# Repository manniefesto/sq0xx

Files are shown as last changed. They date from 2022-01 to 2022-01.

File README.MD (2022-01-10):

# Sq0xx

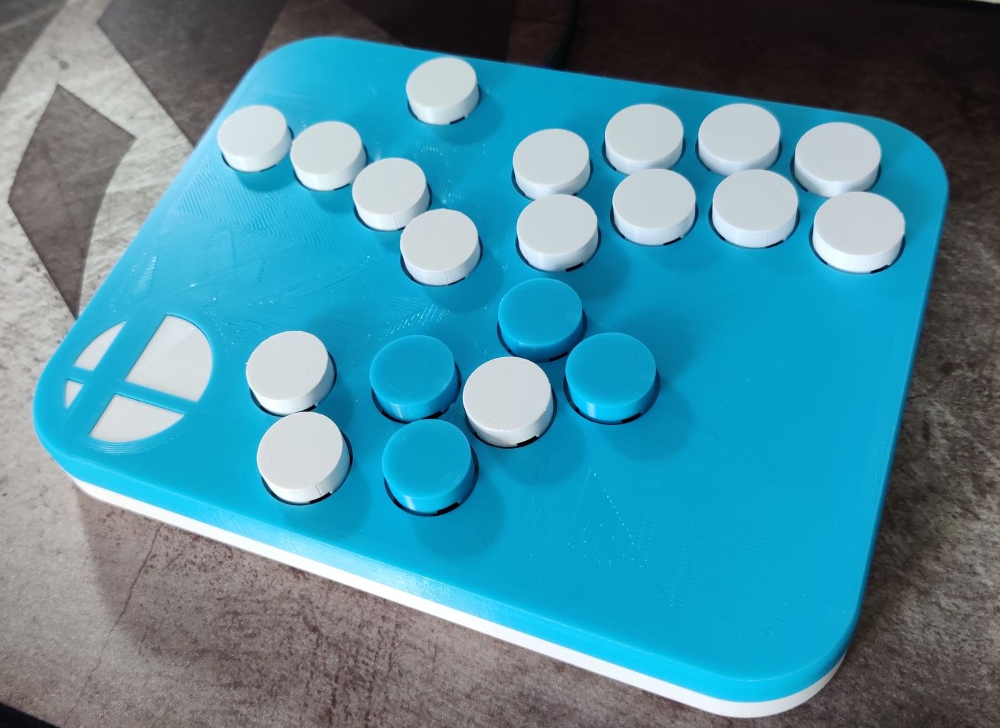
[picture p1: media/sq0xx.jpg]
Image of sq0xx


Squat b0xx.

I've printed and tested V1, there are some fixes in the V2 case files that are untested but should work just fine.

## V1 vs V2
I made a few small changes to the way that the two halves connect.

* Increased the size of the inset to make a tighter fit.
* Moved the magnets closer together.

## 3D Printed parts
* 1 x Top.stl
* 1 x Plate.stl
* 1 x TopLogo.stl
* 1 x Bottom.stl
* 20 x [20mm MX button](https://cdn.thingiverse.com/assets/29/e4/cd/0b/65/20.64mm_Keycap.stl) from the [Fake1](https://www.thingiverse.com/thing:4917086)

## BOM
* PCB, I suggest JLCPCB.
* 20 MX keyboard switches.
* 20 Kailh hot swap sockets.
* Raspberry Pico micro controller.
* M2 Standoffs [Amazon link](https://www.amazon.co.uk/gp/product/B08LDF5SMQ)
* 4 10mm x 3mm magnets [Amazon link](https://www.amazon.co.uk/gp/product/B07QKWBS4S)

## Soldering
All of the components are soldered on to the back of the PCB. The Pico is soldered flat against the board without a socket. I have added break outs for a hardwired GCC cable if required.

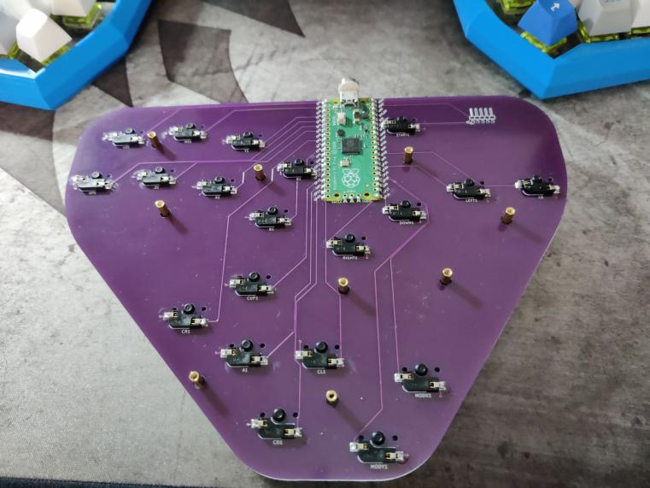
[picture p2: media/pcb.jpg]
Image of pcb


## Firmware
Big shout out to Arte for writing some awesome software, [pico-rectangle](https://github.com/JulienBernard3383279/pico-rectangle)

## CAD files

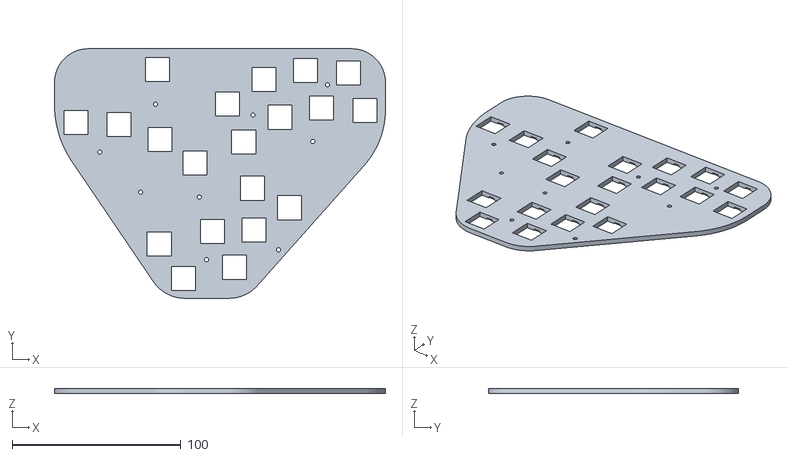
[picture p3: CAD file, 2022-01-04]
Case/V2/Plate.stl
196.1 x 147.9 x 3.00

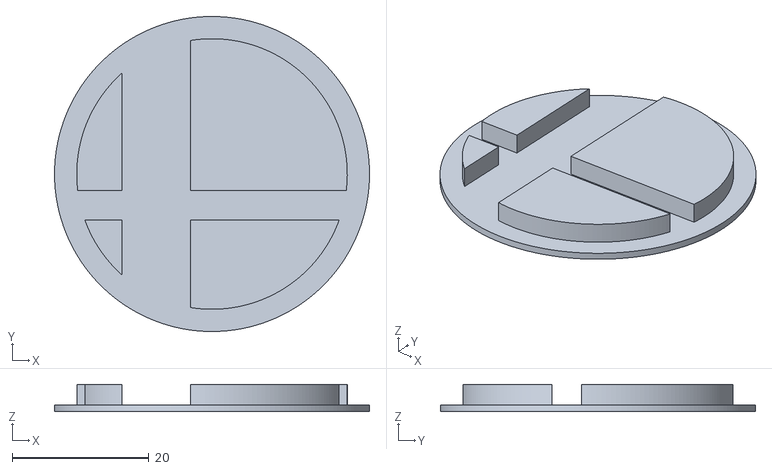
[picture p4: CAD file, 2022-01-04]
Case/V2/TopLogo.stl
46.0 x 46.0 x 4.00

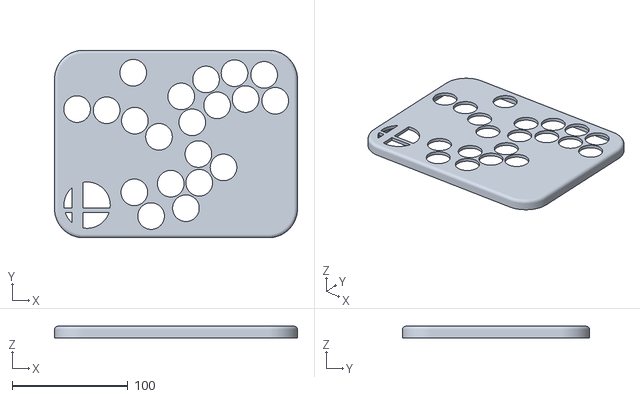
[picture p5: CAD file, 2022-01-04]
Case/V2/Top.stl
210.0 x 162.0 x 10.0

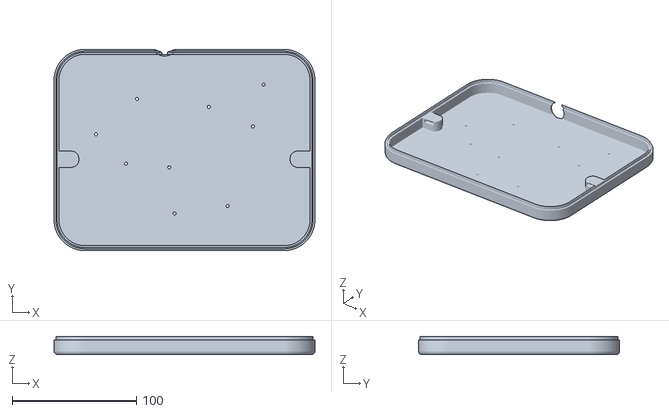
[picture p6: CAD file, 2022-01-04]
Case/V2/Bottom.stl
210.0 x 162.0 x 14.8

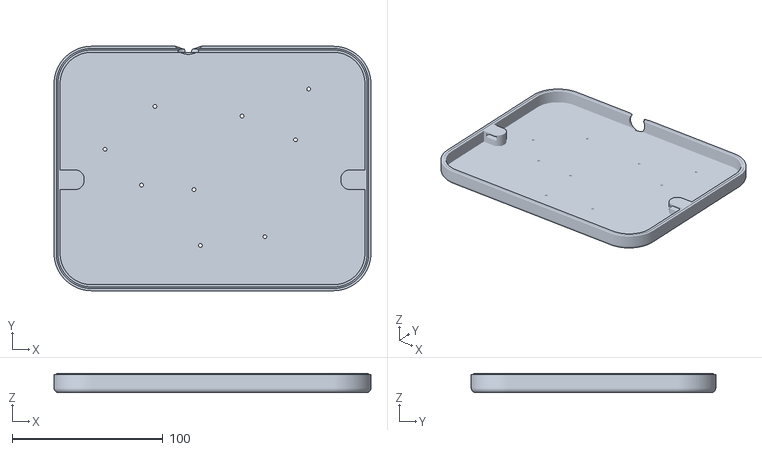
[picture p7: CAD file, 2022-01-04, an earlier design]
Case/V1/Bottom.stl
210.0 x 162.0 x 12.8

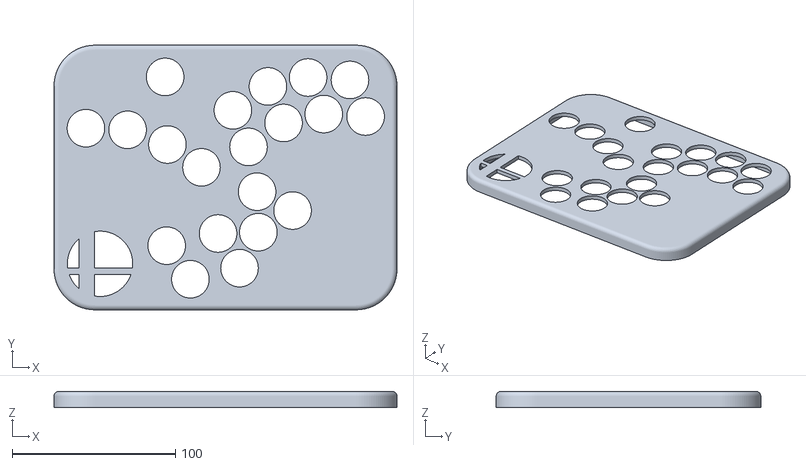
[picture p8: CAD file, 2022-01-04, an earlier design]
Case/V1/Top.stl
210.0 x 162.0 x 10.0

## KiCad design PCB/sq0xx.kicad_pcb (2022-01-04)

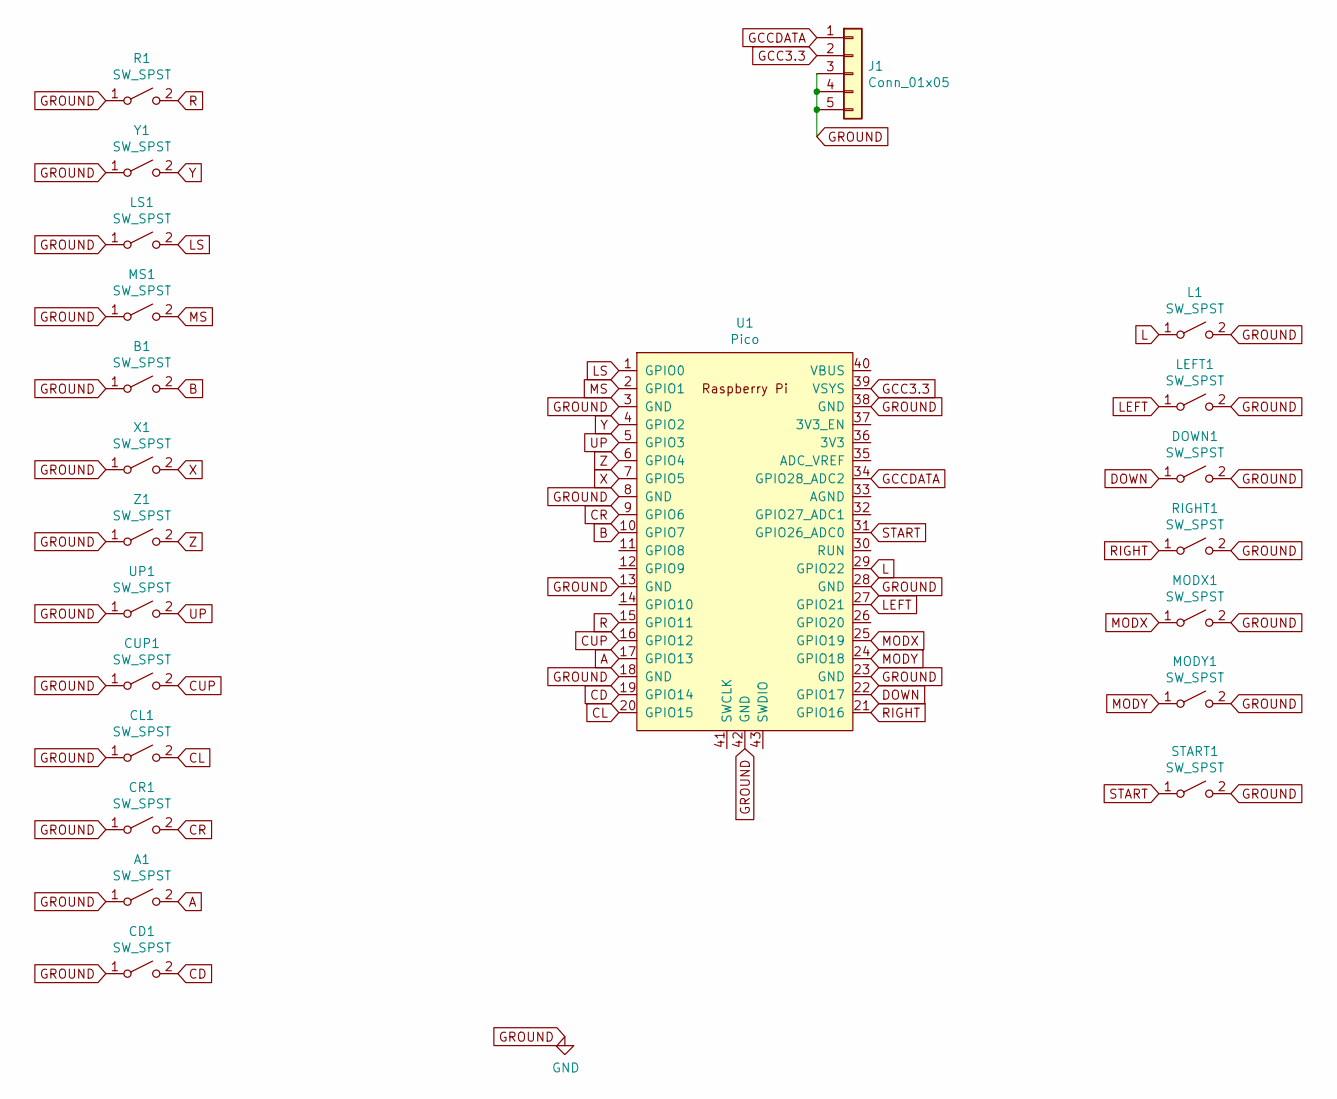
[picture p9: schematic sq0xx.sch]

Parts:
A1: SW_SPST; SW_Hotswap_Kailh
B1: SW_SPST; SW_Hotswap_Kailh
CD1: SW_SPST; SW_Hotswap_Kailh
CL1: SW_SPST; SW_Hotswap_Kailh
CR1: SW_SPST; SW_Hotswap_Kailh
CUP1: SW_SPST; SW_Hotswap_Kailh
DOWN1: SW_SPST; SW_Hotswap_Kailh
J1: Conn_01x05; PinHeader_1x05_P2.00mm_Vertical
L1: SW_SPST; SW_Hotswap_Kailh
LEFT1: SW_SPST; SW_Hotswap_Kailh
LS1: SW_SPST; SW_Hotswap_Kailh
MODX1: SW_SPST; SW_Hotswap_Kailh
MODY1: SW_SPST; SW_Hotswap_Kailh
MS1: SW_SPST; SW_Hotswap_Kailh
R1: SW_SPST; SW_Hotswap_Kailh
RIGHT1: SW_SPST; SW_Hotswap_Kailh
START1: SW_SPST; SW_Hotswap_Kailh
U1: Pico; RPi_Pico_SMD_TH
UP1: SW_SPST; SW_Hotswap_Kailh
X1: SW_SPST; SW_Hotswap_Kailh
Y1: SW_SPST; SW_Hotswap_Kailh
Z1: SW_SPST; SW_Hotswap_Kailh

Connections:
A: A1.2 (B), U1.17 (GPIO13)
B: B1.2 (B), U1.10 (GPIO7)
CD: CD1.2 (B), U1.19 (GPIO14)
CL: CL1.2 (B), U1.20 (GPIO15)
CR: CR1.2 (B), U1.9 (GPIO6)
CUP: CUP1.2 (B), U1.16 (GPIO12)
DOWN: DOWN1.1 (A), U1.22 (GPIO17)
GCC3.3: J1.2, U1.39 (VSYS)
GCCDATA: J1.1, U1.34 (GPIO28_ADC2)
GROUND: A1.1 (A), B1.1 (A), CD1.1 (A), CL1.1 (A), CR1.1 (A), CUP1.1 (A), DOWN1.2 (B), J1.3, J1.4, J1.5, L1.2 (B), LEFT1.2 (B), LS1.1 (A), MODX1.2 (B), MODY1.2 (B), MS1.1 (A), R1.1 (A), RIGHT1.2 (B), START1.2 (B), U1.3 (GND), U1.8 (GND), U1.13 (GND), U1.18 (GND), U1.23 (GND), U1.28 (GND), U1.38 (GND), U1.42 (GND), UP1.1 (A), X1.1 (A), Y1.1 (A), Z1.1 (A)
L: L1.1 (A), U1.29 (GPIO22)
LEFT: LEFT1.1 (A), U1.27 (GPIO21)
LS: LS1.2 (B), U1.1 (GPIO0)
MODX: MODX1.1 (A), U1.25 (GPIO19)
MODY: MODY1.1 (A), U1.24 (GPIO18)
MS: MS1.2 (B), U1.2 (GPIO1)
R: R1.2 (B), U1.15 (GPIO11)
RIGHT: RIGHT1.1 (A), U1.21 (GPIO16)
START: START1.1 (A), U1.31 (GPIO26_ADC0)
UP: U1.5 (GPIO3), UP1.2 (B)
X: U1.7 (GPIO5), X1.2 (B)
Y: U1.4 (GPIO2), Y1.2 (B)
Z: U1.6 (GPIO4), Z1.2 (B)

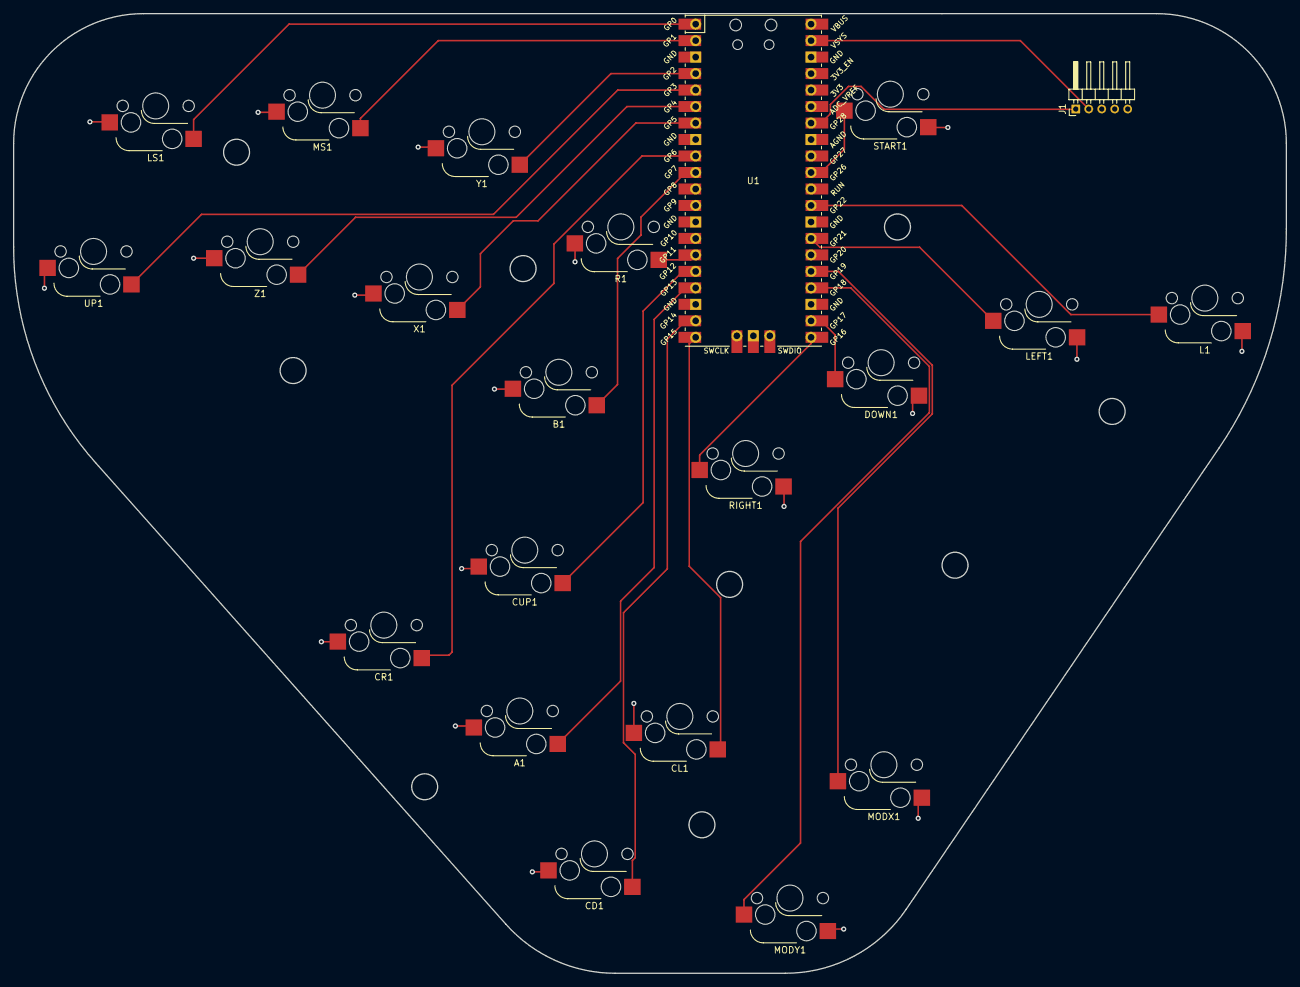
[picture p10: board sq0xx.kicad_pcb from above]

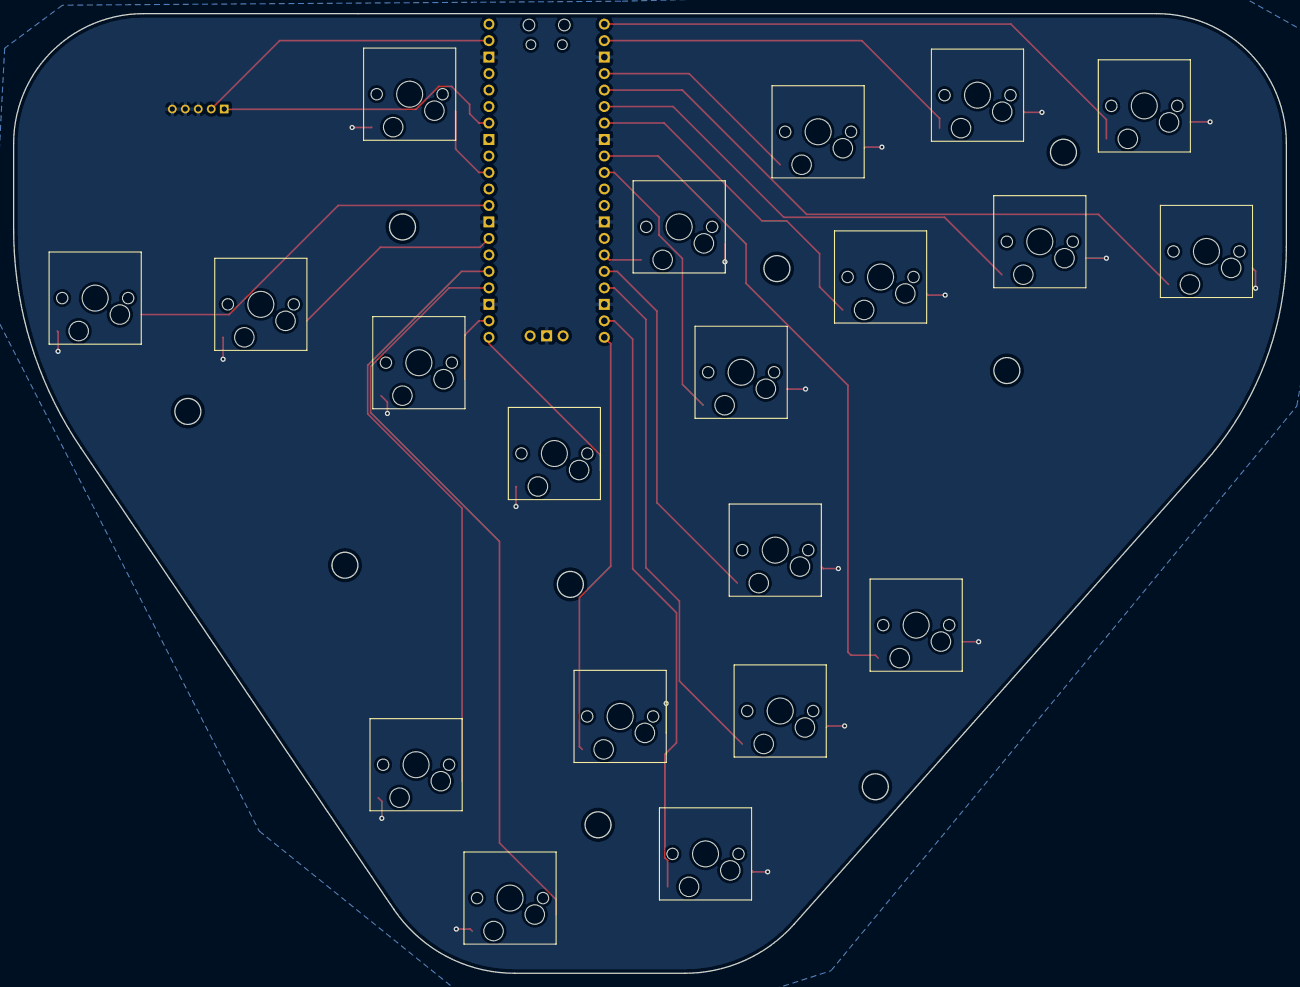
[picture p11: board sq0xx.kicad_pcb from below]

Board: 2 copper layers, 196.1 x 147.9 mm, 22 parts (20 on the bottom side), 23 nets.

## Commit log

2021-12-13 Added draft PCB files
    [sq0xx.kicad_pcb, sq0xx.sch]
2021-12-13 Folder changes and lots of work
    [sq0xx.kicad_pcb, sq0xx.sch]
2022-01-04 Fixed missing grounds
    [sq0xx.kicad_pcb]
2022-01-04 Added case files and readme
    [Bottom.stl, Plate.stl, Top.stl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]
